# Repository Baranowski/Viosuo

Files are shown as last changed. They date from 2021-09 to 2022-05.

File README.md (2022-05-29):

**Note: This is mostly a dump of the project files with very scant instructions.
The keyboard has been adjusted to my hand and probably
wouldn't serve well anyone else. So at this point it's basically a proof of
concept. However, if someone wants to play with this idea I will be happy to
help if I can.**

Wearing both sides

One side hanging

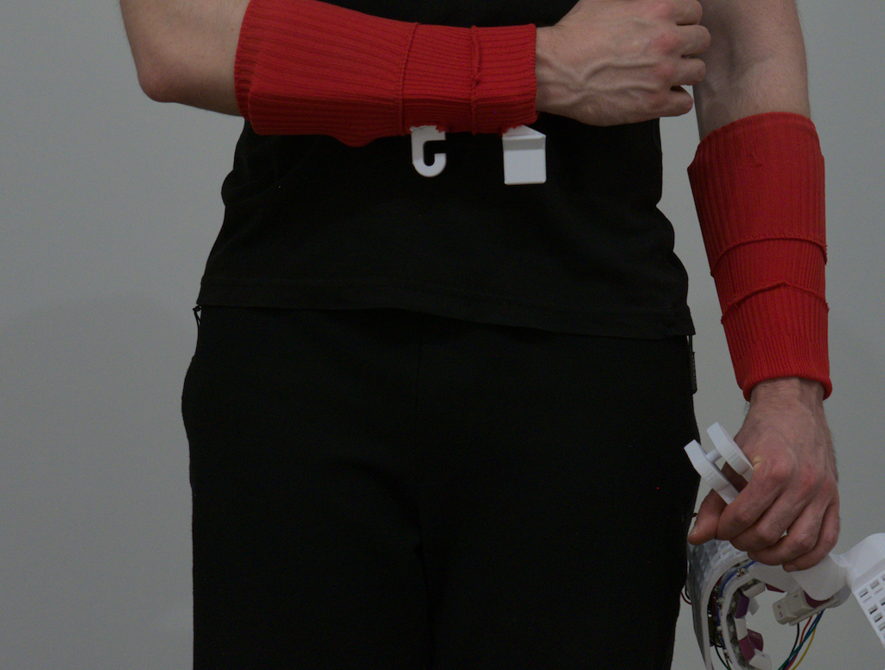
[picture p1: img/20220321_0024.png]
One side removed


Demo
====

Video demo of typing: [https://youtu.be/d8-P9P5Dz6U](https://youtu.be/d8-P9P5Dz6U)

What's this?
============

3D-printable parts of a pretty weird but fully functional keyboard. My design goals:
* It has to be fully usable while walking, since I like to pace back-and-forth
  while thinking
* Even though it's strapped to the arms, it should not hinder basic
  manual tasks that a programmer might need to perform during his work, most
  importantly: preparing and drinking coffee.
* It should be impossible or extremely rare to 'get lost' on the keyboard, i.e.,
  to become uncertain where specific keys are located in relation to the user's
  fingers
* It has to offer all the keys, including modifiers, for normal writing,
  programming and using software such as vim, tmux, etc.
* The typing speed should not suffer _too much_. It might be impossible to reach
  the same speed as on a standard QWERTY keyboards though - some sacrifice is
  acceptable
* (Non-critical) It should look nerdy

Name and pronunciation
======================

Viosuo is pronounced like the [Polish word for
oar](https://translate.google.com/?sl=en&tl=pl&text=oar&op=translate). I chose
this name because an early prototype looked a lot like an oar and was as
uncomfortable as it sounds.

What's in this repo
===================

* The `stl/` subdirectory contains STL files of the most recent design. All of
  them can be easily printed on Ender 3.
* The `viosuo.FCStd` is a FreeCAD file with the entire design. It's done really,
  really badly mostly due to my inexperience, but also because I was working
around the [Topological Naming problem](https://wiki.freecadweb.org/Topological_naming_problem).
* `macros/hole_puncher.py` is a simple FreeCAD macro that for a selectedy Body finds all surfaces that look like they might be inteded for a key and cuts out a 14x14mm square through the middle, intended for an MX switch
* `macros/fc_plumbing.py` is my quickly-abandoned attempt at writing a framework
that would make python scripting in FreeCAD much easier. I still think
somethink like this would be an amazing tool and should be reasonably easy to
create but I'm too lazy to do it myself. I'm including this here since
`hole_puncher` depends on it.
* `zmk/` is my fork of the [ZMK framework](https://github.com/zmkfirmware/zmk)
with a keymap and all the necessary boilerplate for Viosuo added.

How to build one
================

Printing suggestions
--------------------

I used Ultimaker Cura for slicer and printed on Ender 3. Support structure was Tree. Every part was
printed with a Brim for adhesion.

* The Sleeve was printed vertically
* The Connector was printed horizontally, with almost all of its body resting on
  the support structure
* The Palm was printed flat, without any additional rotation. You might have to
  fiddle with the support structure's settings and carefully preview the
  generated gcode to make sure that every hole has enough support.
* The Cover is optional. I printed it upside-down
* The Travel\_bottom and Travel\_top should not be needed at all - I designed
  them quickly when I had to travel and throw my keyboard into a suitcase.

Additional materials
--------------------

* M5x40 bolts and M5 nuts (4x)
* Some kind of elastic sleeve to strap the keyboard to your forearm - I used
  football calf compression socks for boys: https://www.emag.ro/set-1-1-jampieri-rucanor-pentru-baieti-rosu-796830/pd/DFV01TMBM/
* nice!nano (2x): https://nicekeyboards.com/nice-nano/
* Mill Max Low Profile Sockets (2 pairs) - optional if you want to connect your
  nice!nanos somehow else
* batteries (2x) - See the nice!nano page for requirements; I used some no-name: https://www.emag.ro/acumulator-li-po-3-7v-400mah-2-fire-1337/pd/DW87YGBBM/
* 1N4148 diodes (68x)
* XDA keycaps (68x)
* MX-compatible switches (68x) - I used gateron greens
* wires
* heat-shrink tubes

Wiring
------

Here are some pictures of the left-hand side's wiring. Please note that I have
soldered sockets to the nice!nano upside-down. There is a very simple reason for
that: I made a mistake.

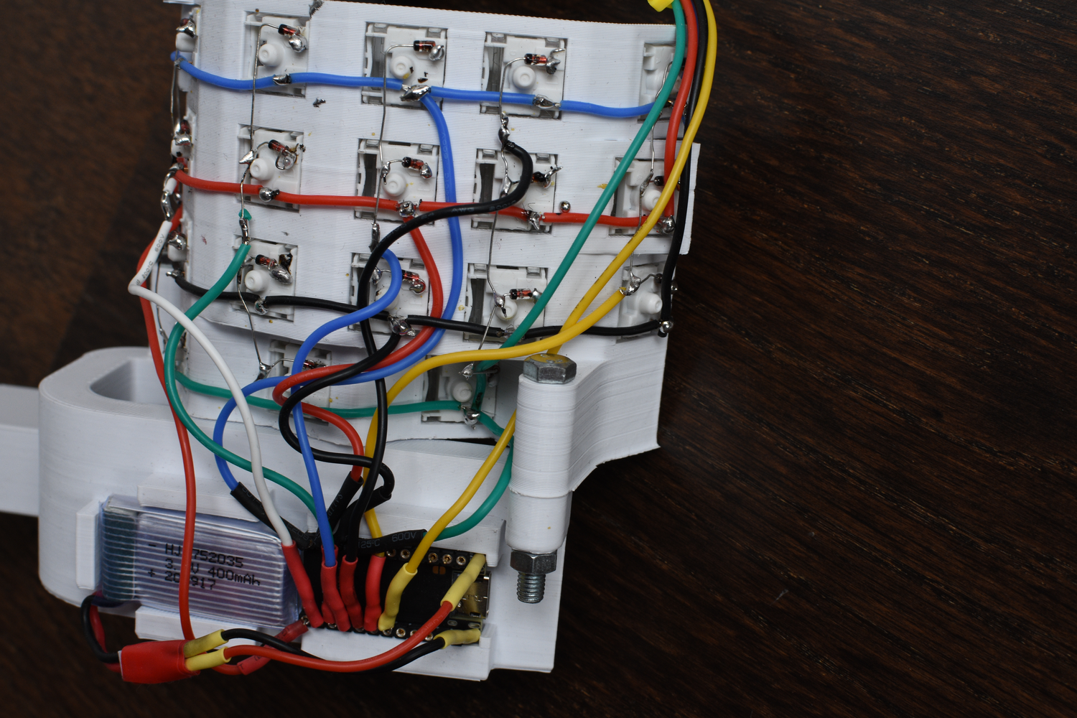
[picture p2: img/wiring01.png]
wiring01


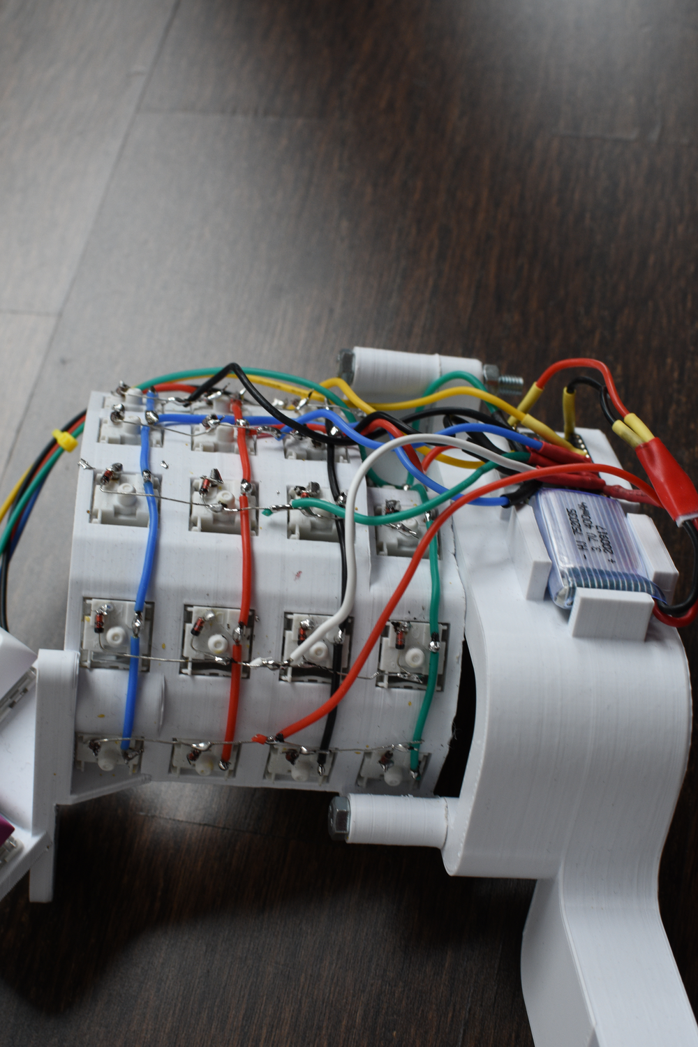
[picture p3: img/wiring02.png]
wiring02


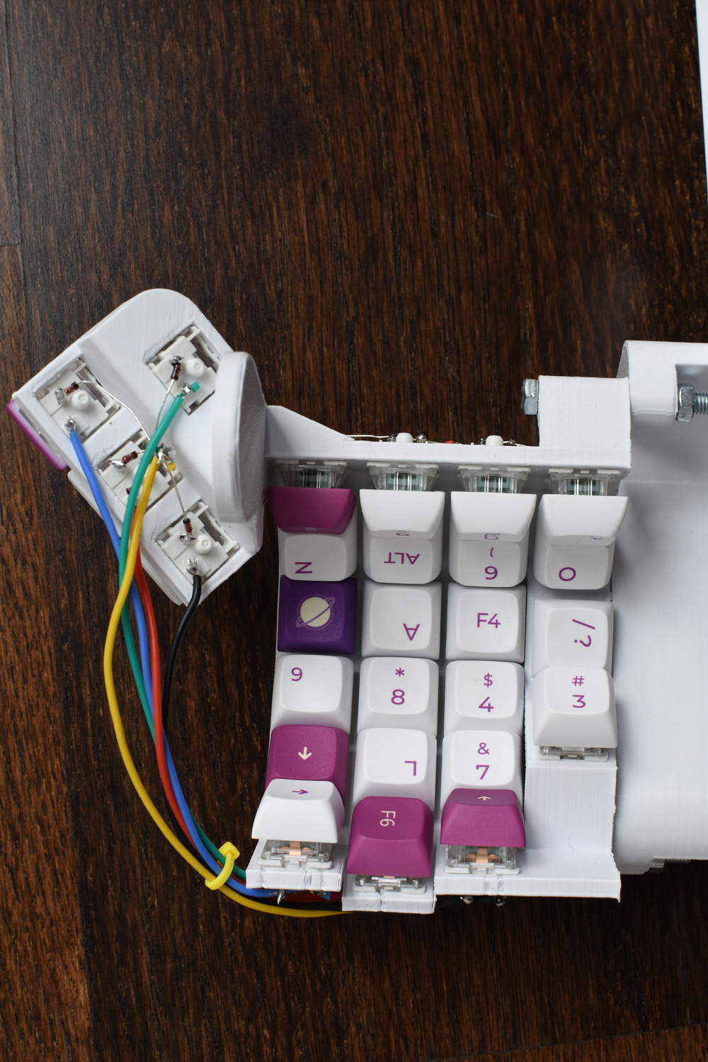
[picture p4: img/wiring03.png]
wiring03


In the pictures above each wire responsible for a column (i.e., set of keys
operated by a single finger) ends with a black heat-shrink tube. Every row-wire
ends with a red heat-shrink tube. The thumb cluster is treated as another row
but this one ends with a yellow heat-shrink tube.

In order to plug the wires into the Mill Max sockets soldered to nice!nanos I
did the following:

1. Put the heat-shrink tube on each of the wires
1. Gather the diode legs cut off while soldering the keyboard
2. Solder one to the chip-facing end of each of the wires
3. Bend the end of each of those legs at the right angle. The length of the bent
   piece should be such that it fits into the socket but doesn't stick out much.
4. Slide the heat-shrink tube all the way towards the bent part and apply heat.
   That way the wires should not short when they are plugged in next to each
   other.

Sleeve
------

I simply put the 3D-printed "Sleeve" part into my textile sleeves, cut out the
holes for the protruding elements and then stapled (with an office stapler) the surrounding area of the
textile sleeve so that the holes do not rip.

Building firmware
-----------------

I used ZMK firmware. My patches live in this repo as the 'zmk' submodule. In
order to clone this repo together with the firmware run either

    git clone --recursive https://github.com/Baranowski/Viosuo

or

    git clone https://github.com/Baranowski/Viosuo
    cd Viosuo
    git submodule update --init --recursive

Then you can follow the standard zmk building instructions: https://zmk.dev/docs/development/build-flash

The name of the shield is viosuo and so the specific commands to build this
firmware are:

    west build -d build/left -b nice_nano -- -DSHIELD=viosuo_left
    west build -d build/right -b nice_nano -- -DSHIELD=viosuo_right

TODO improvements
=================

Separate columns
----------------

It would be much better if each column (i.e., a set of keys operated by a single
finger) could be printed separately and then they could be joined together by a
couple long bolts. The longer bolts would replace the currently used M5x40 (I
used M5x40 simply because that's what I had at hand). That way you could iterate
much faster while experimenting with variations in the keys layout. I haven't
yet figured out how the thumb cluster could be attached in a similar way.

Software for desigining columns
-------------------------------

One thing I love about Dactyl-Manuform is how customizable the design is, thanks
to the scripts that generate STL files for any reasonable parameters chosen by
the builder.

It should be possible to write similar software for Viosuo's columns. This again
would make it much faster to iterate on the layout and would allow more people
to adjust the keyboard to their hands.

Angles between keys and protruding keys
---------------------------------------

The angle between the 3rd and 4th row (counting from the palm) is too flat - I
often confuse the two rows. A sharper angle would be more practical. Perhaps
they keys of the 3rd row should protrude, similarly to how the top keys on the
pinky column protrude. Unfortunately, I came up with the idea of protruding keys
quite late in the game when I didn't want to fiddle with the arrangement of the
3 main columns. The above idea of separately-printable columns would have helped
with that.

Cover attachment
----------------

The cover seems to be necessary - without it the electronic components catch
very easily on clothing. However, the method of attaching the cover should be
smarter - currently it's really a hassle because the bolts joining all the
elements together are quite deep underneath the cover.

Comfort in different positions
----------------------------

Currently I find the keyboard very comfortable when standing or walking but I
choose to take it off whenever I want to sit down. A better design would allow
to comfortably rest the keyboard in your laps and on or underneath a desk. 

I believe this should be pretty easy to do with modifications to the "Connector"
part. Perhaps the hook on the "Sleeve" part would also have to be reversed.

License
=======

Um... I don't know. I will pick one if there is any interest. It will be
something open and permissive.

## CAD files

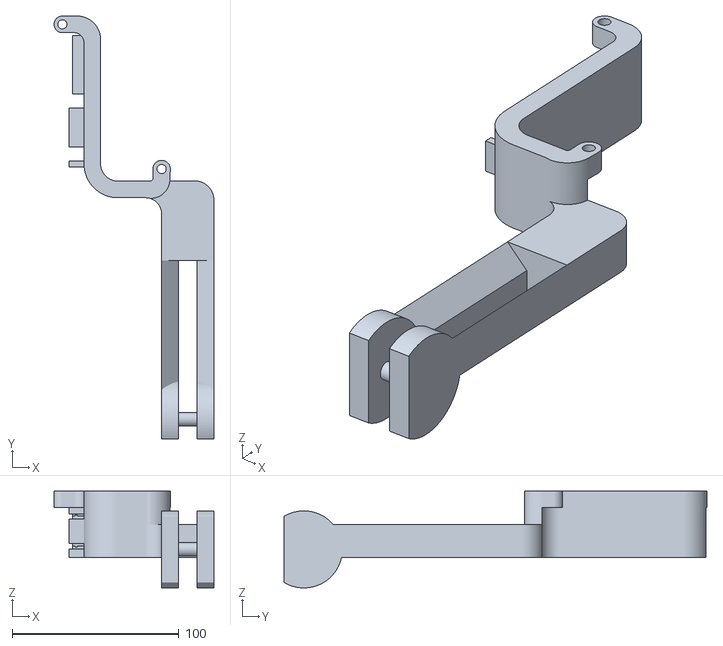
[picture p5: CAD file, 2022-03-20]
stl/connector.3.1.stl
95.9 x 253.7 x 58.1

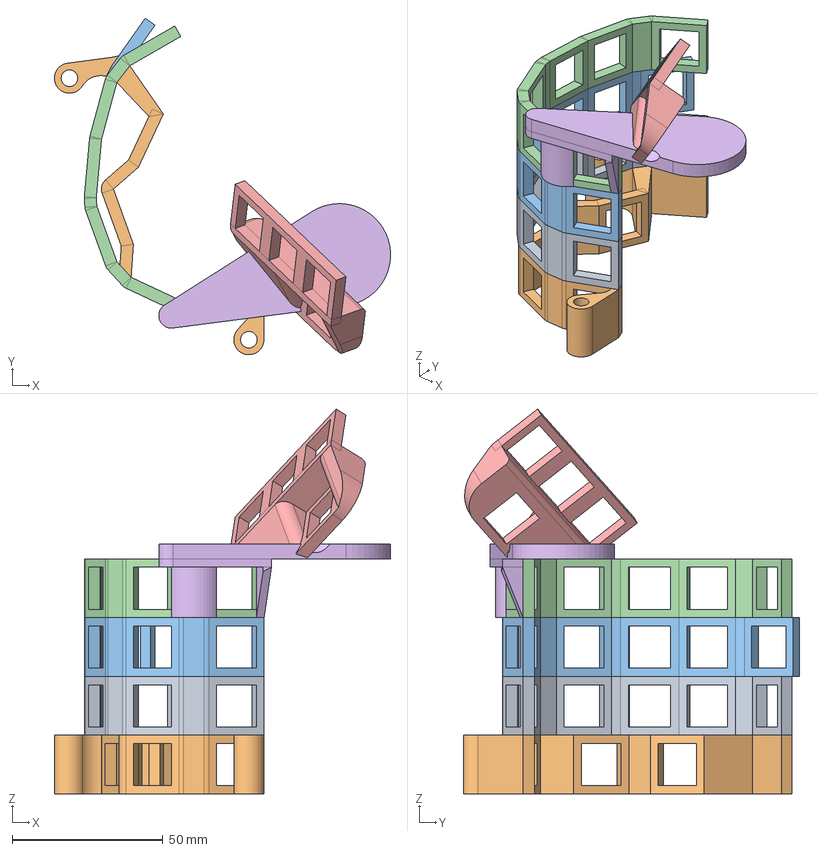
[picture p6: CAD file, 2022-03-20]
tests.FCStd
111.6 x 111.7 x 127.8 mm
Ring column
Pinky column
Middle column
Index column
Rocket launching cluster
Circle

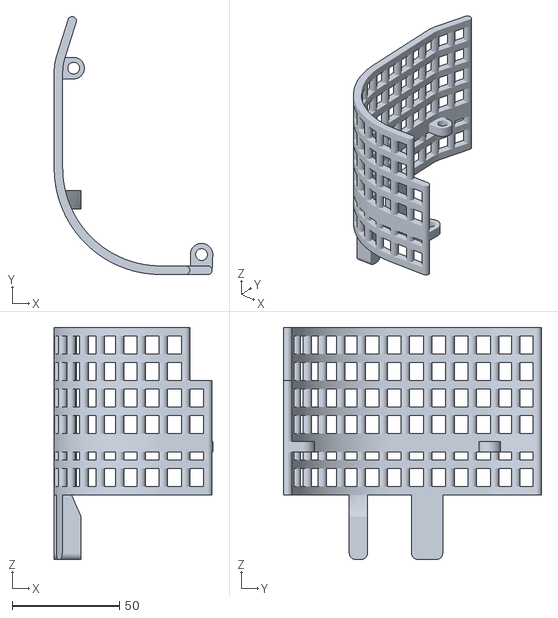
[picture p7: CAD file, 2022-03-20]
stl/cover.1.1.stl
73.9 x 120.1 x 108.0

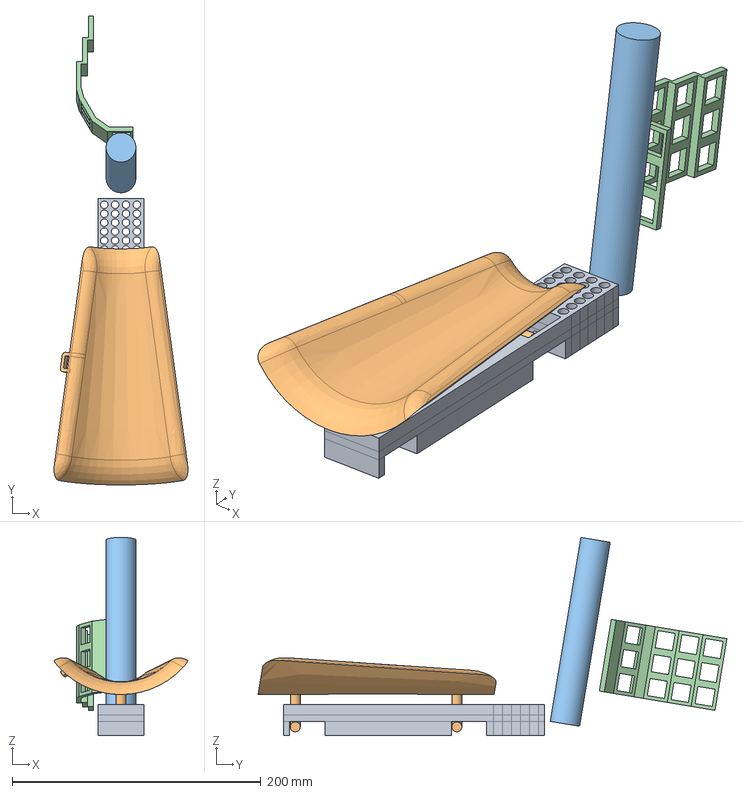
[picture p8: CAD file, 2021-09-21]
viosuo.FCStd
107.7 x 377.3 x 159.4 mm
Rail
Arm part
Pole
Main keys

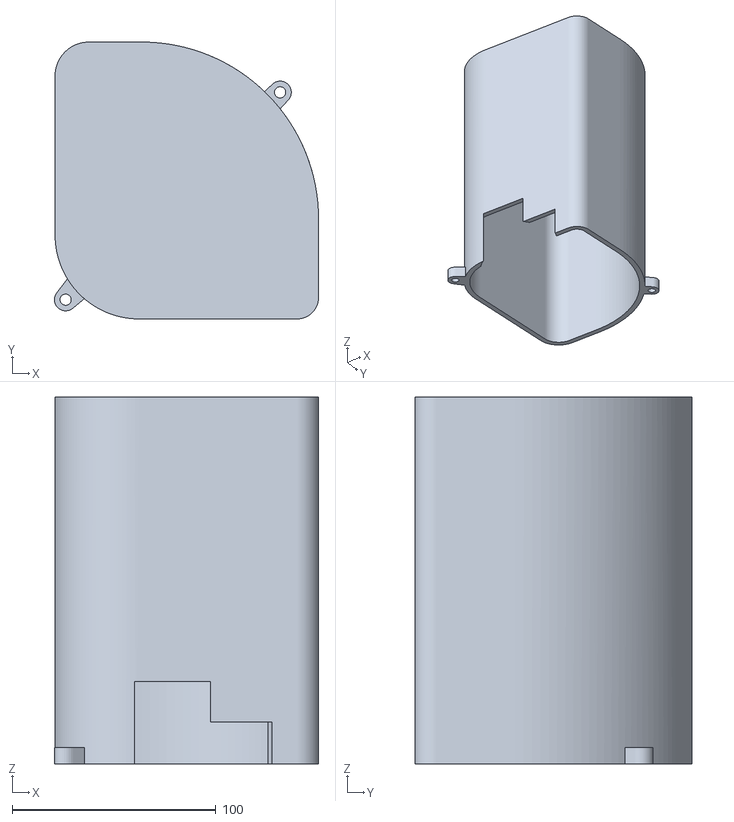
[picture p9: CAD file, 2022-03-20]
stl/travel_top.1.1.stl
129.6 x 135.8 x 180.0

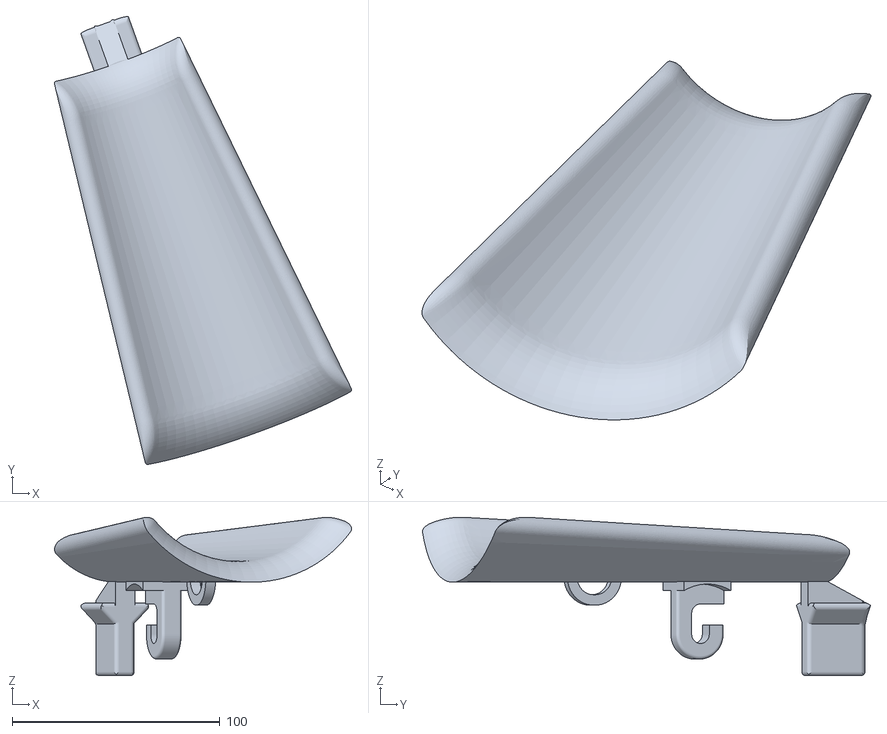
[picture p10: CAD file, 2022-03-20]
stl/sleeve.1.4.stl
142.9 x 215.6 x 76.3

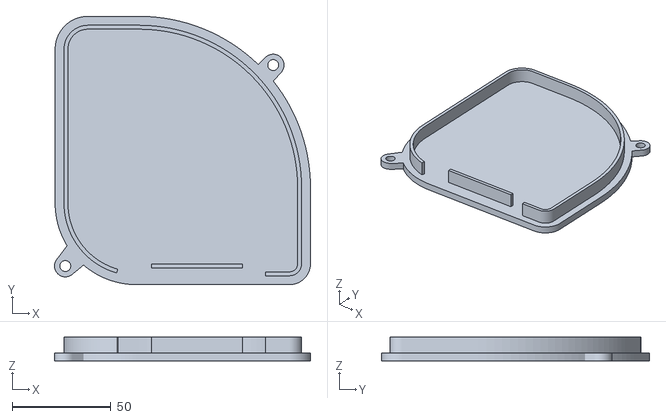
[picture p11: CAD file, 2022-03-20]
stl/travel_bottom.1.1.stl
129.6 x 135.8 x 12.0

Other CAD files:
stl/palm.3.3.stl

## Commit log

2021-09-13 From python script
    [viosuo.FCStd]
2021-09-13 Arm sleeve with catchers and strap hole
    [viosuo.FCStd]
2021-09-14 Rail top and middle
    [viosuo.FCStd]
2021-09-18 screw holes in the rail
    [viosuo.FCStd]
2021-09-21 Arm support: fused and filletted
    [viosuo.FCStd]
2021-09-21 Main keys plate (no holes)
    [viosuo.FCStd]
2021-09-21 Holes for main keys
    [viosuo.FCStd]
2021-09-23 test.FCStd: angle tester and single column testers
    [tests.FCStd]
2022-03-20 macros/hole_puncher.py (seems to work)
2022-03-20 Remove print()s
2022-03-20 tests.FCStd: main_keys.3.0
    [tests.FCStd]
2022-03-20 rocket_launcher.3* (3x3 cluster with varying spaces and angles)
    [tests.FCStd]
2022-03-20 palm.1.1
    - fix screws positioning
    - rocket cluster:
    * shift to the left a bit
    * rotate counterclockwise
    - knuckle support:
    * thicker
    * more centered on the knuckle (hopefully)
    [tests.FCStd]
2022-03-20 connector.1.0 and sleeve.1.0
    [tests.FCStd]
2022-03-20 connector.2.0, sleeve.1.1, palm.1.2
    [tests.FCStd]
2022-03-20 sleeve.1.2 and connector.2.1 (bigger axle, connector more economic)
    [tests.FCStd]
2022-03-20 sleeve.1.3 - move the hook farther back
    [tests.FCStd]
2022-03-20 palm.1.3: smaller circle, less offset from the rocket launcher
    [tests.FCStd]
2022-03-20 palm.2.0
    * Removed rocket cluster for now
    * 3x6 + 4 keys
    * Farther away from the axis
    * Gentle adjustment to the rotation
    * Very big circle
    General idea: Make the palm flat when writing, eliminate too aggressive
    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
2022-03-20 palm.2.1 - circle is not circle anymore, much narrower
    [tests.FCStd]
2022-03-20 palm.2.2
    * rocket cluster only 3 keys and pushing outside
    * the not-circle slightly bigger
    [tests.FCStd]
2022-03-20 palm.2.3
    * 2.5 mm closer to the axis
    * pinky column aligned with the others
    [tests.FCStd]
2022-03-20 palm.2.4: 3rd and 4th pinky key at 45 deg angle
    [tests.FCStd]
2022-03-20 palm.2.5: pinky 3rd and 4th keys stepped rather than curved
    [tests.FCStd]
2022-03-20 palm.2.6: pinky 4th key is angled (45 deg) and still stepped
    [tests.FCStd]
2022-03-20 palm.2.7: shift closer to the elbow by 1cm
    [tests.FCStd]
2022-03-20 palm.3.0 - screws much closer, better connection with rocket launcher
    [tests.FCStd]
2022-03-20 palm.3.1: move the far screw hole closer
    [tests.FCStd]
2022-03-20 connector.3.0: new shape & screw positions
    [tests.FCStd]
2022-03-20 cover.1.1: cut a bit from the top on the palm's end
    [tests.FCStd]
2022-03-20 connector.3.1: tabs protecting the chip 2mm instead of 1mm
    [tests.FCStd]
2022-03-20 palm.3.3: 4th rocket launching key
    [tests.FCStd]
2022-03-20 travel_top.1.1 and travel_bottom.1.1: second screw slot
2022-03-20 Add most recent stl files
    [connector.3.1.stl, cover.1.1.stl, palm.3.3.stl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]
